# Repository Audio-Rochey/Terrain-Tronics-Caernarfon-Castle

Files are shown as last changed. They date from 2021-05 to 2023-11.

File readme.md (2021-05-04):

# TerrainTronics-Caernarfon-Castle

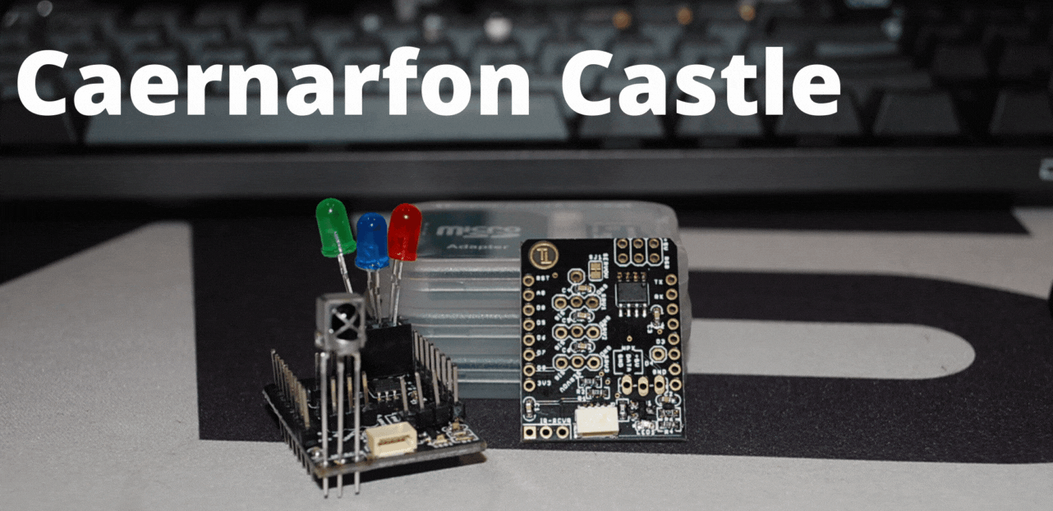
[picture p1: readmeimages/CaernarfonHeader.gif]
Image of Caernarfon Castle and the Small Circuit Board


## Version Data
Current release is version PG1.0. All features have been tested individually using standard Arduino libraries.

## Introduction

The TerrainTronics Caernarfon Castle board is designed to bring interaction to your terrain. The Caernarfon castle offers:
- Ability to drive 3x Servo Motors
- Infra-Red Remote Control Receiver
- 3 Onboard LED's
- Outputs for Neopixel (WS281x) Addressable LED's
- KeepAlive Circuit (pulls ~100mA every few seconds to keep a USB battery pack awake)
- QWIIC I2C Connector to connect to external sensors etc
- 

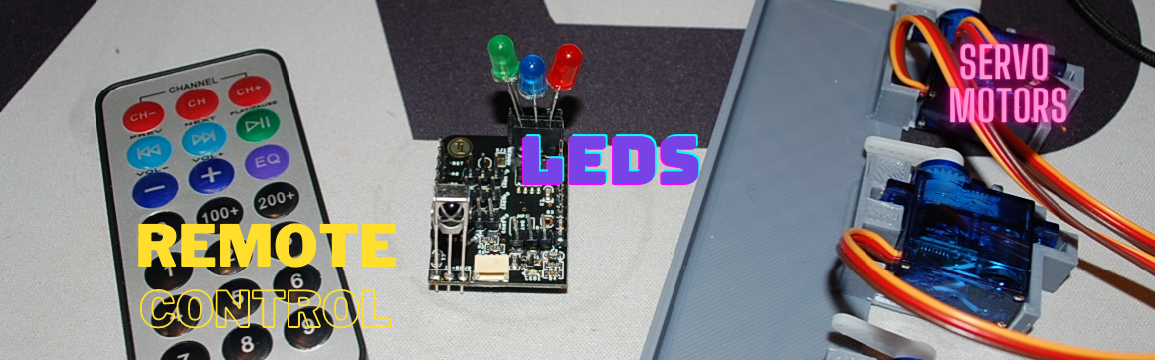
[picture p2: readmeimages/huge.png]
Image of the external features enabled by Caernarfon Castle


Onboard is the ability to drive 3 Servo Motors for moving gates, doors and other light bits of terrain, work with 3 LED's directly, and address a long chain of others, Change all the lights on your terrain RED when the situation changes, and with an IR Reciever, so you can use any old remote control to send messages to your terrain to respond. 

This makes it the ultimate tool for a DM (Dungeon Master) or GM (Games Master) to make their worlds interactive, to create puzzles with real, visible outcomes - prizes or punishments!

Code examples are constantly being developed and added here. 

**Please Note** - a Wemos D1 Mini board is required to control the Caernarfon Castle board. The Wemos D1 Mini is a small microcontroller board (using ESP8266) that has a standardized small form factor, wifi capability (if you want to use it) and the ability for it to be programmed using the Arduino programming environment. Whilst installing the Arduino programming environment is required to configure your setup - you can avoid the need for actual programming by copy/pasting some of the examples here.

## Pinout of the board

<table class="tg">
<thead>
  <tr>
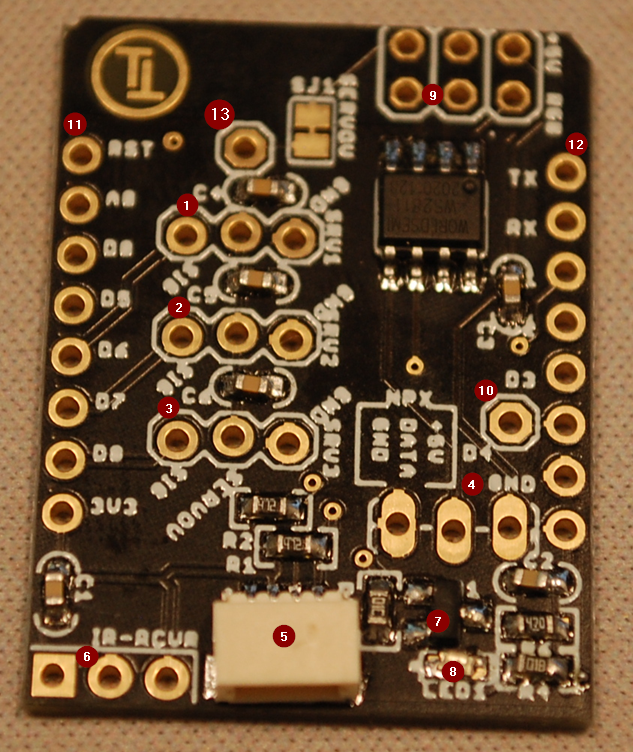
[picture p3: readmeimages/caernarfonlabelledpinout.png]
    <th class="tg-0pky" rowspan="14"></th>
    <th class="tg-0pky">Feature</th>
  </tr>
  <tr>
    <td class="tg-0pky">1. Servo Output (signal, power supply (5V), Ground) </td>
  </tr>
  <tr>
    <td class="tg-0pky">2. Servo Output</td>
  </tr>
  <tr>
    <td class="tg-0pky">3. Servo Output</td>
  </tr>
  <tr>
    <td class="tg-0pky">4. Neopixel output (GND, DataOut, +5V)</td> 
  </tr>
  <tr>
    <td class="tg-0pky">5. QWIIC I2C Connector</td>
  </tr>
  <tr>
    <td class="tg-0pky">6. IR Receiver - VS1838B - OUT, GND, VCC (+3.3V)</td>
  </tr>
  <tr>
    <td class="tg-0pky">7. KeepAlive Circuit</td>
  </tr>
  <tr>
    <td class="tg-0pky">8. Power Indicator (5V)</td>
  </tr>
  <tr>
    <td class="tg-0pky">9. LED Outputs from the first Neopixel</td>
  </tr>
  <tr>
    <td class="tg-0pky">10. Pin D4 output</td>
  </tr>
  <tr>
    <td class="tg-0pky">11. Left hand side strip to the Wemos D1 board</td>
  </tr>
  <tr>
    <td class="tg-0pky">12. Right hand side strip to the Wemos D1 board</td>
  </tr>
  <tr>
    <td class="tg-0pky">13. Alternative Servo Power Rail</td>
  </tr>
</thead>
</table>

| Pin | Notes about pin | Functionality |
|-----|---|---|
| D0  | No PWM possible | KEEPALIVE |
| D1  | Often used as SCL | I2C-SCL |
| D2  | Often used as SDA | I2C-SDA |
| D3  | No Pulldown allowed | NEOPIXEL OUT  |
| D4  | LED. No Pulldown Allowed | LED |
| D5  | Often used for SPI-CLK | IR IN |
| D6  | Often used for SPI-COPI | SERVO1 |
| D7  | Often used for SPI-CIPO | SERVO2 |
| D8  | No Pullup Allowed (Fail Boot). | SERVO3 |

the "notes about pin" come from the Wemos D1 Mini documentation. Effort has been made to make the Caernarfon Castle board compatible with other boards in the Terrain Tronics ecosystem, please note however that the Harlech Castle board cannot be used with the Caernarfon, as the IR IN and SPI-COPI (Controller Out Peripheral In) are used for different uses. However, Neopixels can be used in place of Harlech boards if needed.

## Unboxing and Assembly

Image of Caernarfon Box Contents

The Caernarfon Castle board is delivered without the pins having been soldered, however, you should find the pins in the package. This is to allow you to populate whichever pins are needed for the functionality that you are working towards, or, if system height is a concern, to solder wires directly into the holes.

The strips on the left and right hand side of the board are mandatory, to be used to stack and connect to a Wemos D1 Mini. Most Wemos D1 Mini boards are sold without soldered connectors either. In my experience it's easier to put female headers on the Wemos D1, then downard facing male connectors on the Caernarfon board. 

In the box, you will find:
1x Caernarfon Board
2x 40pin Pin headers
2x 8pin long leaded female headers
1x VX1838B IR Reciever

## Functionality

### Servo's (not included)
Image of an SG90 Servo
For motors that can turn an arm between 0 and 180 degrees, servo motors can be used. Servo motors have been used in model aircraft and train sets for years. They are quite easy to use, as you set the angle of deflection needed, and the servo motor will turn to that angle, and using it's own internal feedback, hold that position. The controller, or your software doesn't need to be concerned about measuring or holding the angle etc - simply tell the servo (using code) where to turn to - and it just does!
In the demo code, it's used as a gate to hold a boulder from rolling down and hurting the adventurers.

3 servo motors can be connected to the Caernarfon Castle board and can be addressed in Wemos D1 Arduino code on pins D5, D6 and D7. A library called Servo.h (a standard Arduino library) is used and can be downloaded from the internal GUI.

Servo's can be connected on to the 3-pin strips in the middle of the board. They should be connected as SIGNAL-POWER-GND. Most servo's are colour coded in Orange (Signal), Red (Power), Brown/Black (Ground). I've had some success with SG90 Servo's. They are the smallest kind on Amazon, but very usable.

### LED's (not included)
Image 3mm LED and of a Neopixel
The board has a WS2811 onboard. This is a chip that the wemos d1 board talks to with LED values. It has 4 outputs. 3 of them are for LED's and one (DOUT) is used to send on to the next in the chain. Such a daisy chain of LED's can pull a lot of current (power), so you may need an external 5V power supply that can provide enough current. For a handful of LED's, you should have no trouble.
Pin D3 is used to send data. The Adafruit NEOPIXEL library can be used to send data.

### I2C Output compatible with Sparkfun QWIIC and Adafruit Stemma QT (Connector onboard)
Image of Closeup of the connector
The board has a standardized I2C connector (4 pin SH connector). The SDA and SCL Pins (used for I2C) are mapped to pins D1 and D2. There are two 4K7Ohm resistors used as pullups. As this is just a connector, external devices will have to be programmed as and when you need them.
Breakout cables are available from Amazon, Sparkfun and Adafruit.

### USB Powerbank Keepalive circuit
Image of board with the size of the circuit
A transistor wired to put power through a small resistor is used to pull a surge of current every few seconds. This is used to convince some USB Power Banks to stay on, as many will go into a sleep mode and stop delivering power if there isn't enough power being drawn. The Keep Alive circuit pulls around 90mA-110mA when activated on pin D0.
No specific library is required to toggle pin D0, but be aware that the board is going to get hot quite quickly if you leave it on! 5V at ~100mA means approximately 0.5W of power will be dissipated in a device smaller than a grain of rice. Switch is on for a second, then off again! :)
In my code, I use the "ticker" library (#include <Ticker.h>). When you use a ticker function, you essentially set a software based timer that will run the code every few seconds (or however long you like). The accuracy isn't perfect, but it should be set to be often enough to keep a battery pack alive! :)

### Infra Red Reciever for remote control (included)
Image of the connector soldered correctly
Image of the device will the pins highlighted
VX1383B IR recievers are bundled with the kit. This IR reciever is designed to recieve most standard remote control signals and convert them into the electrical pulses that are decoded by the Wemos D1 Mini. 
Data is brought in on pin D5. 
I've used the IRremoteESP8266: IRrecvDemo to prove functionality. (it spits out the code driven by the remote on the computer screen). I then take that code (e.g. "FF30CF")
and change my code to respond in some way to that code - change the light, move a servo etc.
This allows you to use an off the shelf low cost remote control, or even recycle that remote control that in the junk drawer to control your terrain!
Care should be taken in which way the receiver is connected. Please see the image for reference. The reciever can be wired offboard if you want to hide your controller deep under the foam but show the IR reciever on a specific part of the terrain. 

## Schematic and Theory of Operation
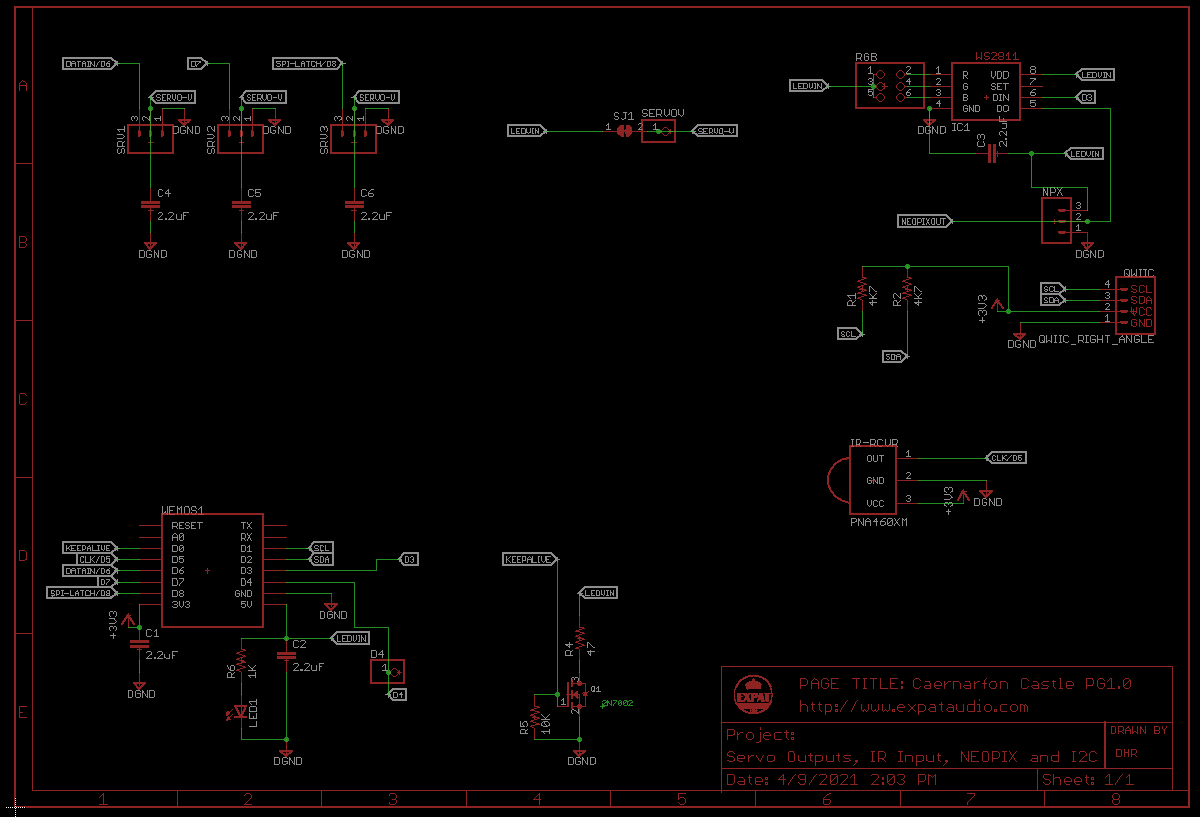
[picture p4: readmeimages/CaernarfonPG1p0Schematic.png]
Caernarfon Castle Board PG1p0 Schematic Caernarfon Schematic


[PDF OF THE SCHEMATIC](Caernarfon_Schematic_PG1p0.pdf)

** The text below is from the Conwy board -- need to rewrite ** 
The board functions a current source and 4 current mirrors.
R1,R2 and Q1 sets the reference current in the circuit.
Q2 through Q5 then mirror that current if they can. So an LED connected between the +5V (or your battery positive voltage) and the Drain (the top) of the transistor Q2-Q5 will switch on, then only allow the same amount of current through it that goes through Q1. E.g. if Q1 is set up for 10mA, then regardless of the color of the LED, only 10mA will be passed through it.

As mentioned in section 1 – each color LED drops a different voltage, but many are rated for the same brightness at a specific current.

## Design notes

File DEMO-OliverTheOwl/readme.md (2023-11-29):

# Oliver the Owl - Made by Terraintronics

IMAGE ALT TEXT HERE(https://www.youtube.com/watch?v=9bKIzAbPux4)

Oliver was inspired by WallyDM's Prismatic Owl puzzle.

The entire scene is powered by an 18650 Battery and Charger, available from TerrainTronics (https://www.tindie.com/products/32915/)

The USB Output of the board is connected to Oliver himself, using a USB cable and a hole in the floor.
A Direct 5V output from the board drives a Wemos D1 Mini that has a Harlech Castle 8ch LED Driver on top for driving the LED's that are around the terrain itself.

In the base, along with the battery is the Wemos D1 + Harlech, then each of yellow flickering LED's are connected to it. The setup code is simple and available on this gituhub folder.

## Oliver's Construction

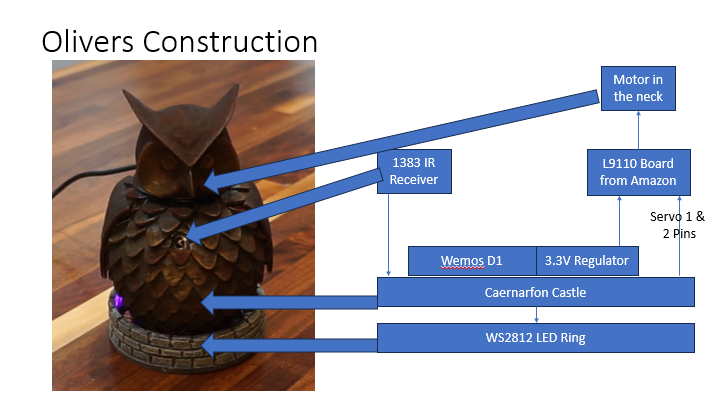
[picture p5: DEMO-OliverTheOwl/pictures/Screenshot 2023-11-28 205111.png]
Olivers Construction


Lightburn laser cutter files for Oliver are available from the special URL you receive when you buy from Terraintronics.

His base has a circular ring of WS2812 RGB LED's. They are soldered with wirewrap wire, then wire wrapped to a Caernarfon board.

The Caernarfon board connects is Servo Signal 1 and 2 pins to an L9110 Motor Driver Module from Amazon. That provides the right signals for the motor.

The motor is designed to run from 3.3V, so we need to drop the 5V from the USB on the Wemos D1 to 3.3V on the motor. The Wemos D1 already has a voltage regulator onboard, but I didn't want to risk pulling to much power and causing the Wemos D1 to crash! So an AMS1117 regulator module (again, Amazon was used).

> Written with [StackEdit](https://stackedit.io/).

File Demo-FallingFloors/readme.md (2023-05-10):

# Terrain Tronics Gauntlet Challenge!

The contents of this directory go along with a video from 

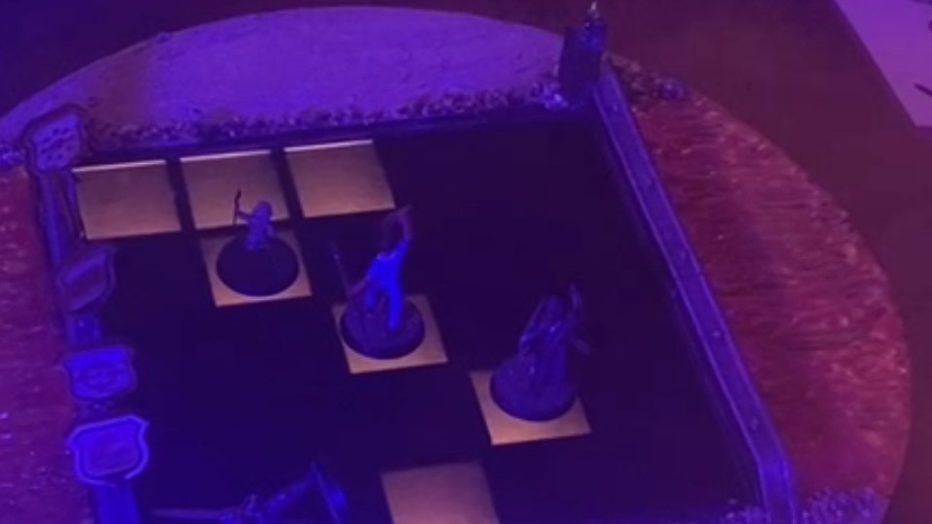
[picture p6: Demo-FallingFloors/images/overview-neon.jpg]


## Features

- 50 RGB LED's in an array of 25 cells, each with 2 RGB LED's in them.
- Ir Remote control for the DM that can:
* Reset the playfield with a random, hidden path
* Remove 1 of 3 options (if DM wants to challenge players with a riddle, skillcheck etc)
* Step to the next row.

## What's in this directory?

- Arduino code to run on the WemosD1 Mini. (ino file, bin file etc). The BIN file can be uploaded, AS IS, using the TerrainTronics upload tool.
- SVG / Lightburn files for the foam and wood parts to be cut out.
- 3D printable files (STL) for parts of the bridge, and the "pizzaswitchandsimpleUSBconnector"

## How does all this work?
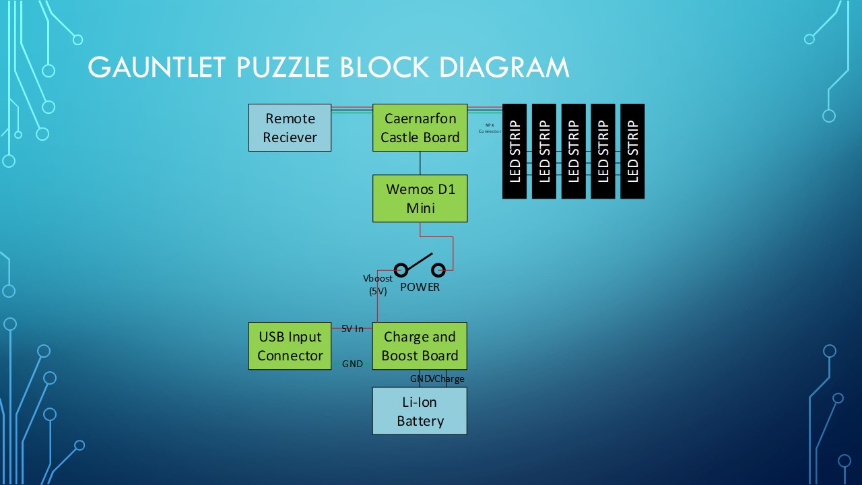
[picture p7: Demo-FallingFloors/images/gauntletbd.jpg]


### Brains and Lights
The playfield is made up of a string of RGB LED's (WS2812B RGB LED's), easily available from Amazon. I picked 60 per Meter, so that a pair of them roughly takes 30mm, close enough to the typical D&D 25.4mm spacing.

The brain is the Arduino compatible Wemos D1 Mini. Based on the infamous ESP8266 Wifi processor, the D1 Mini has a lot of power, a lot of capabilities, small form factor and fairly priced on Amazon.

On top, acting as an interface to the IR Remote control receiver and the interface to the RGB LED's is a Caernarfon Castle PCB board from TerrainTronics. It comes pre-assembled and tested, the only work you have to do is soldering the pins you want to connect to the Wemos D1 Mini.

I typically set the Wemos D1 with Female Headers and use the Caernarfon board with Male headers pointing down into the Wemos D1.
You'll also need to add headers for the NPX Output connector. (NeoPixel - a nerdy term for those RGB LED's) and the IR Receiver.

### Power
I had more fun trying to work out the power tree of this darn thing!
I used a rechargable Lithium Ion battery in my build. If I did it again, I would look for a battery that could support at least 2000mAH. (milli amp hours).

The Chinese electronic module makers have started selling "charge/discharge boards" - these are awesome because they handle all the battery charging concerns. You bring in 5V (from, say, a USB source), you connect your battery (typically a 3.7Volt) and it has an integrated booster, to kick in the 3.7V up to 5V.

WS2812B RGB LED's all require 5V supplies. They are a nuisance! :)

- The USB input connector is always connected to the Charge/Discharge board. That makes sure that even if the lights are off, you can charge the terrain.
- The power switch sits between the output of the CH/Disch board and the Wemos D1 Mini/Caernarfon combination.

## Software

The Arduino IDE is used for developing the software, if you want to tweak it or use it with a different remote control.
You'll need to download the following files:
### 

 - [Caernarfon-FloorPanelProto.ino](https://github.com/Audio-Rochey/Terrain-Tronics-Caernarfon-Castle/blob/main/Demo-FallingFloors/Caernarfon-FloorPanelProto.ino)
 - [buttonfunctions.h](https://github.com/Audio-Rochey/Terrain-Tronics-Caernarfon-Castle/blob/main/Demo-FallingFloors/buttonfunctions.h)
 - [buttonfunctions.ino](https://github.com/Audio-Rochey/Terrain-Tronics-Caernarfon-Castle/blob/main/Demo-FallingFloors/buttonfunctions.ino)

Setting up the Arduino IDe to support the Wemos D1 Mini can be seen in this video: https://www.youtube.com/watch?v=TgE-Op0UvxE

The software is fairly understandable, but if you're struggling, you're welcome to find terraintronics on facebook and ask any questions on the facebook group.

## Physical Build

Lightburn files for laser engraving are in this directory, along with SVG conversions of them. The disc is actually 300mm in diameter, a little less than 12 inches.

> Written with [StackEdit](https://stackedit.io/).

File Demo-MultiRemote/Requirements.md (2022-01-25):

## Caernarfon Castle "Universal" Remote Control code.

Designed to be the default code that ships on TerrainTronics sourced Wemos D1 boards. The code is made for arduino and has 3 files that are part of the code.

Arduino remote

The buttons on the remote control do the following:

| Button | Code | Function |
| --- | --- | --- |
|Prev|FF22DD|Motor A One Direction by 15 degrees |
|Next|FF02FD|Motor A Other Direction by 15 degrees |
|VOL-|FFE01F| Global Brightness Control - (Default Max Power) |
|VOL+|FFA857| Global Brightness Control + (Default Max Power) |
|0|FF6897| All LEDS OFF |
|1|FF30CF| Motor A Toggle 180 Degrees |
|2|FF18E7| Motor B Toggle 180 Degrees |
|3|FF7A85| Motor C Toggle 180 Degrees |
|4|FF10EF| All Lights Red |
|5|FF38C7| LED Strip Flicker like candles |
|6|FF7A85| Lava Effect |
|7|FF42BD| TBD |
|8|FF4AB5| TBD |
|9|FF52AD| TBD |

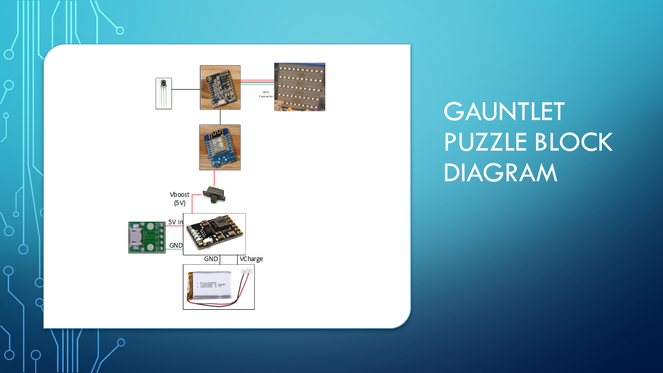
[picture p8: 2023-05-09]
Demo-FallingFloors/Puzzle Part Pictures.png

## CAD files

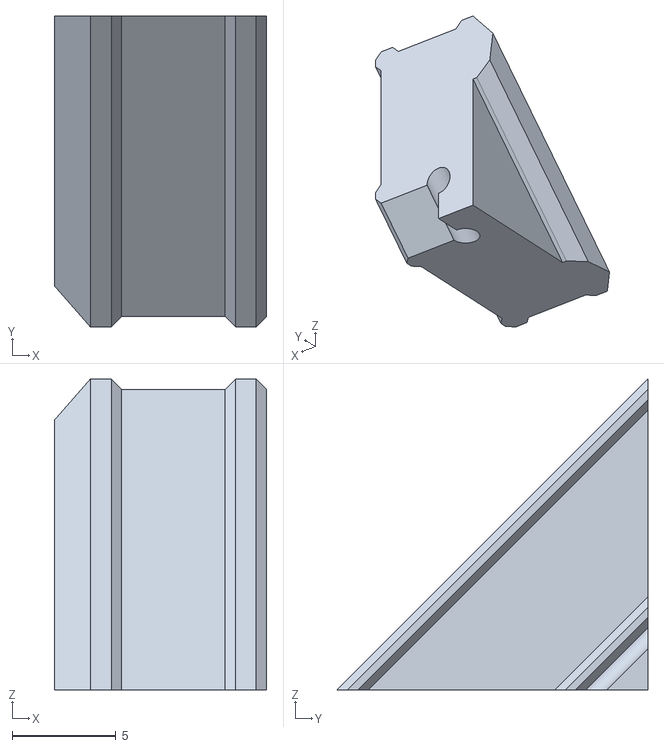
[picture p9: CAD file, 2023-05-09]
Demo-FallingFloors/norsebridgecapleft.stl
10.2 x 15.0 x 15.0

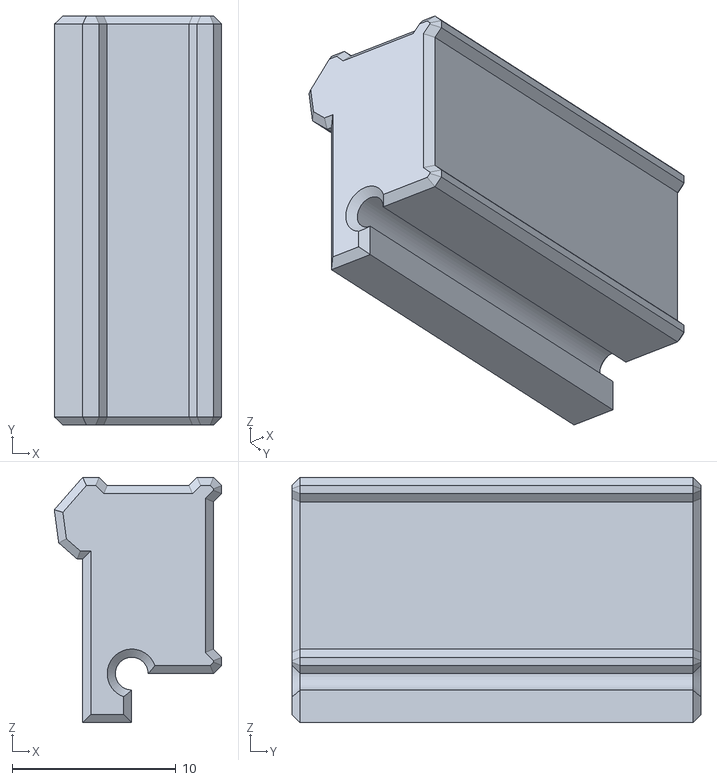
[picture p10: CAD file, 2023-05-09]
Demo-FallingFloors/norsebridgesegment.stl
10.2 x 25.0 x 15.0

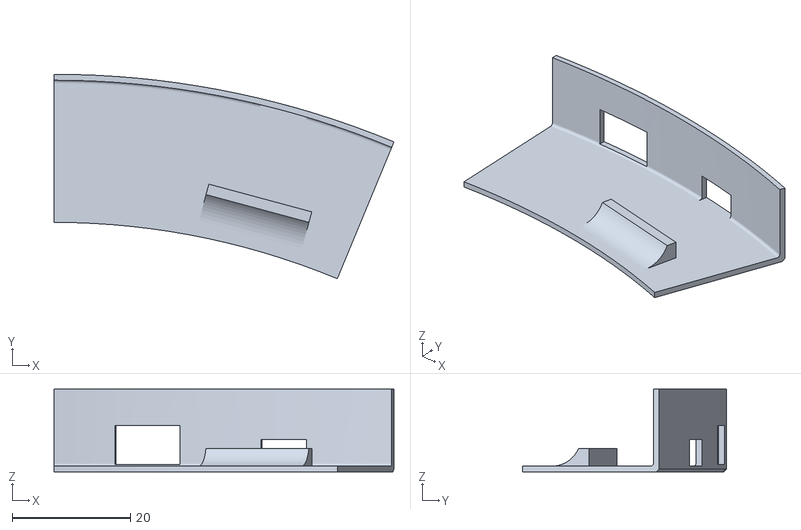
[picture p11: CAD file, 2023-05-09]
Demo-FallingFloors/pizzaswitchandsimpleusbconnector.stl
57.4 x 34.5 x 14.0

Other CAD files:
Demo-FallingFloors/norsebridgecapright.stl

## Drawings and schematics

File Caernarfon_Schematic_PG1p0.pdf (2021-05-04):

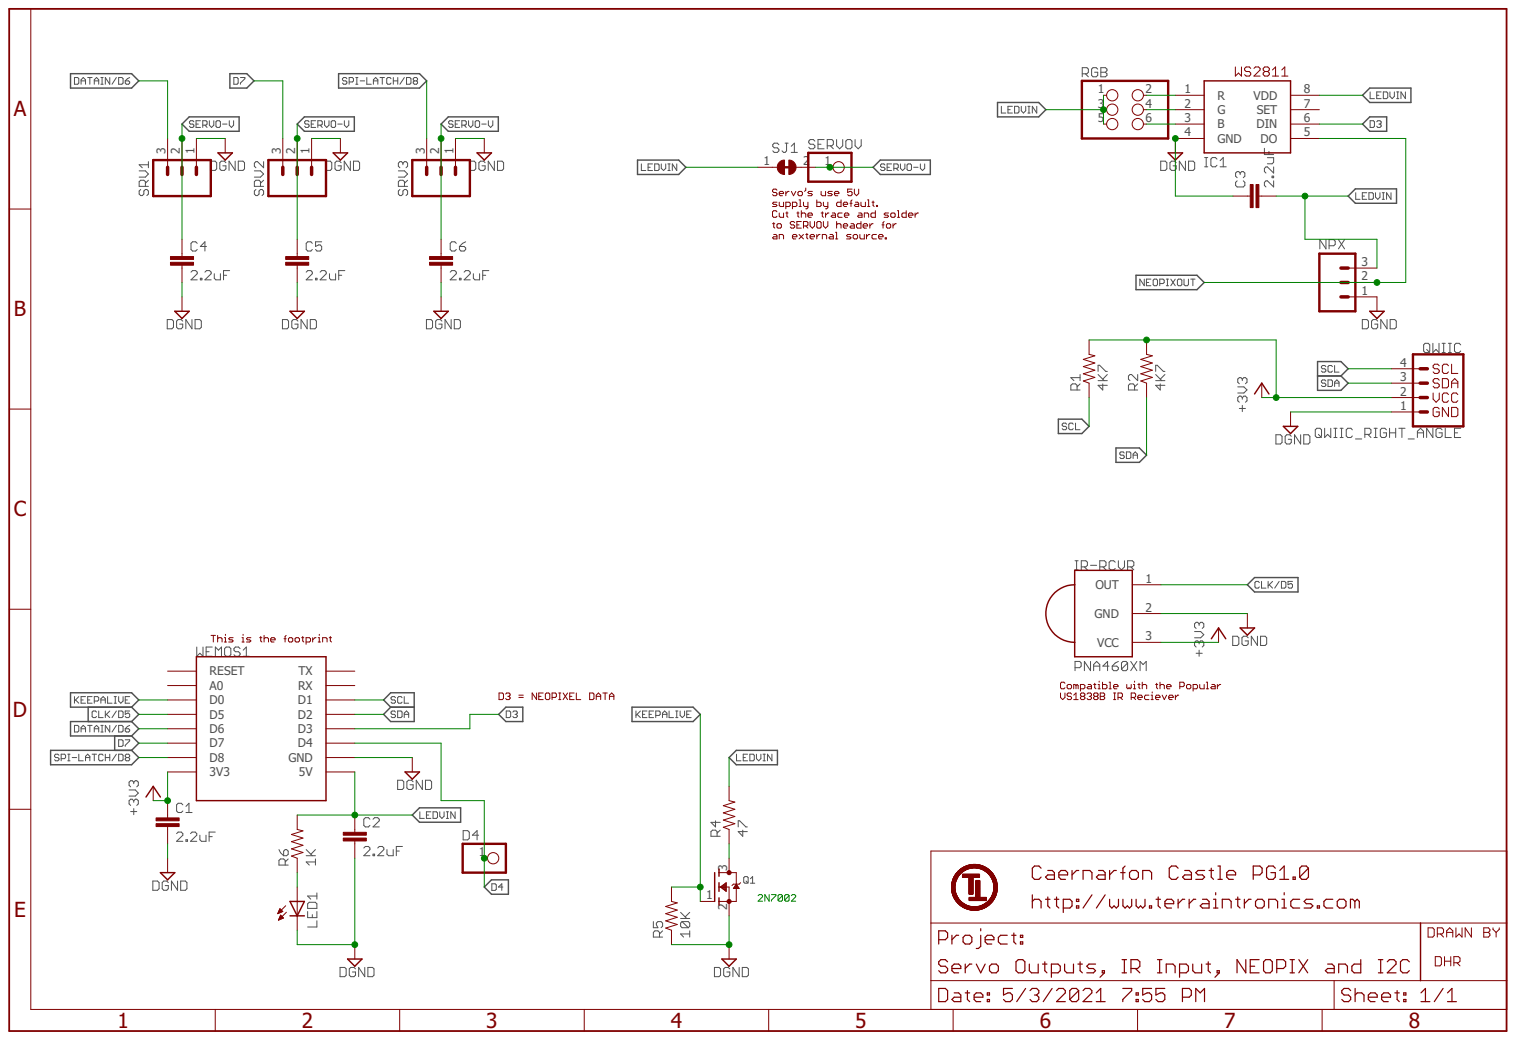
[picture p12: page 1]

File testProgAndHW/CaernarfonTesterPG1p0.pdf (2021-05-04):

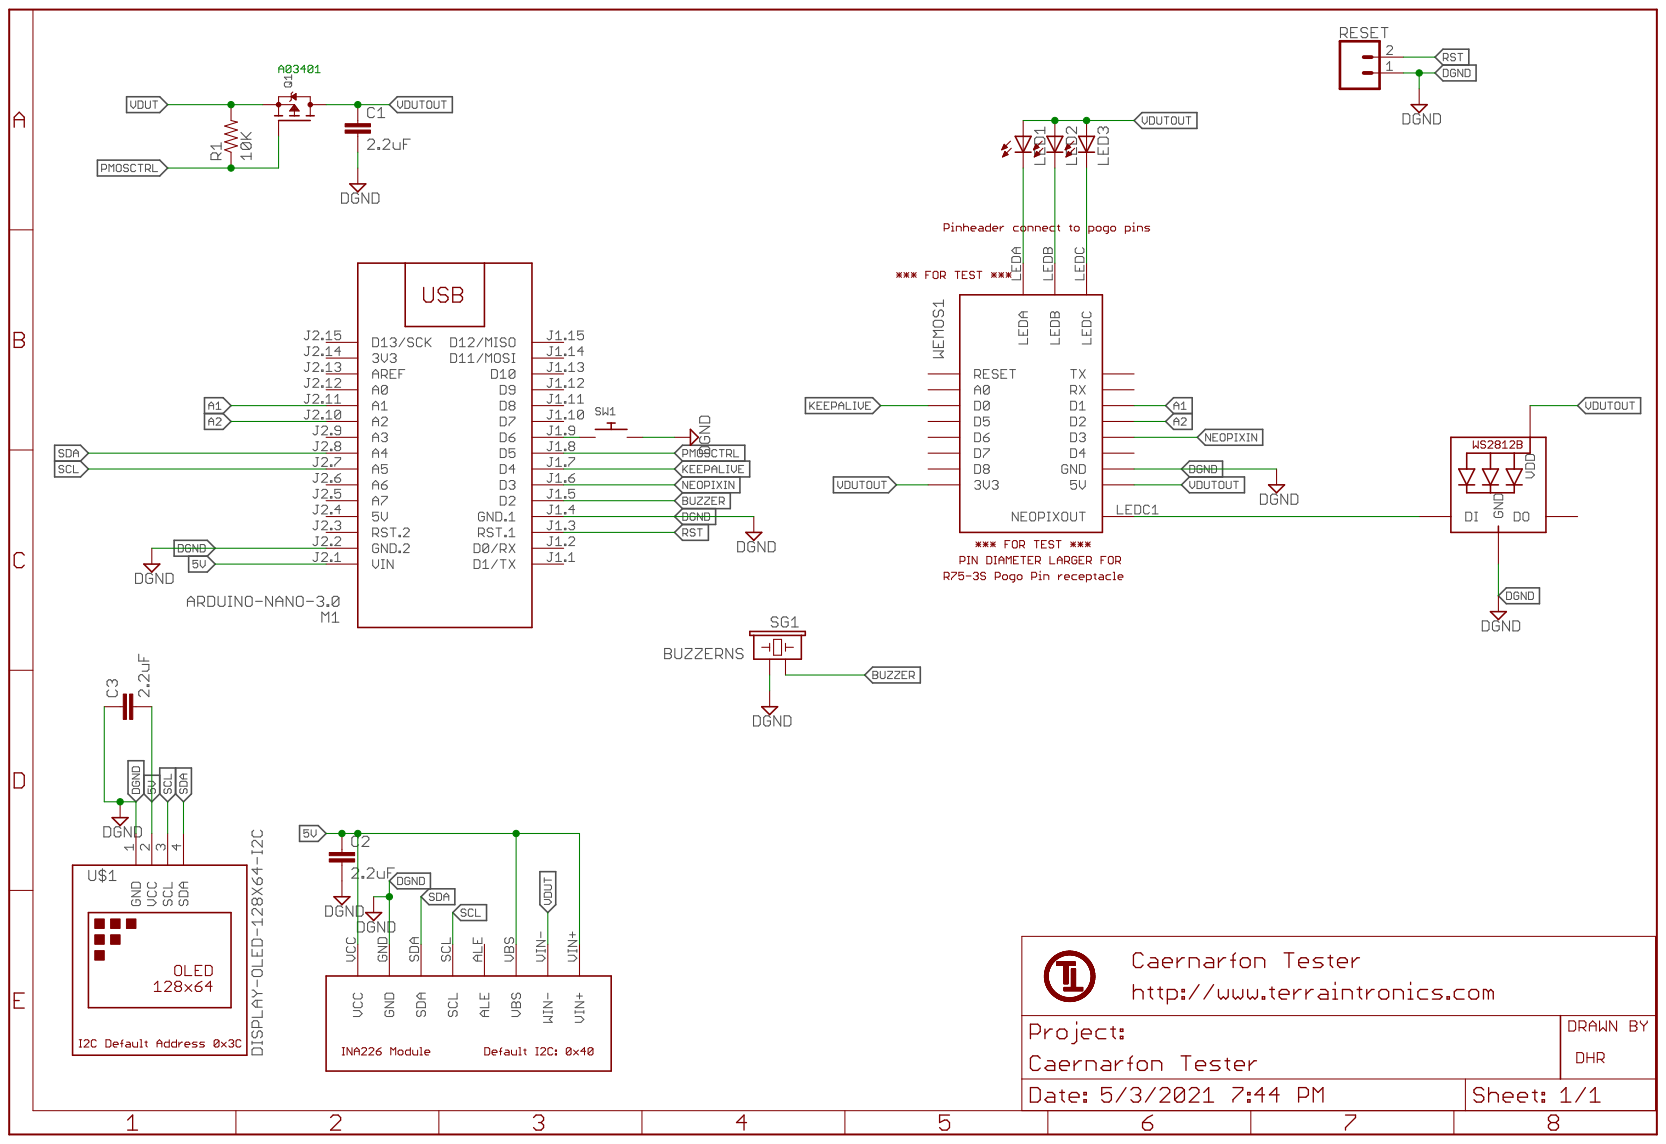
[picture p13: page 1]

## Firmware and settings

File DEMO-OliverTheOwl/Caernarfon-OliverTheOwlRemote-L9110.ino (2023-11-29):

/*
 * 1/24/2022 -- building upon the initial version.
 * This code uses 2 external files within arduino and will define the functionalty for almost every button the remote.
 * Here are the requirements:https://github.com/Audio-Rochey/Terrain-Tronics-Caernarfon-Castle/blob/main/Demo-MultiRemote/Requirements.txt
 * 
 * I followed this video to learn how to split the files in arduino: https://www.youtube.com/watch?v=BdstuZP6l5E
 * However, rather than namign files .cpp, i used INO.
 * 
 * This is the work done for Oliver the Owl (the actual NPC himself, not the room he's in!)
 * Wemos D1+ Mini +_ Caernarfon Castle, then Servo signal 1 and 2 are connected to the inputs to a 
 * 
 * Description of states:
 * ledState Zero is All Lights Off
 * ledState One is all Red.
 * ledState Two is flicker. (which gets updated in the main loop.
 * ledState Three is lava
 * ^^^ this was previously used to toggle the states.
 * 
 * trapOneState between 0 and 1 used to 
 *  * This work is based on the Servo for ESP8266 and the IRremoteESP8266: IRrecvDemo 
 * 
 * Wifi library is used to put it to sleep ASAP. Addd Feb 1st 2022. * 
 * 
 * Dafydd Roche - 2/1/2022
 * 
 * Remote control to switch on some gates.
 * https://amzn.to/2Qc9BI0
 * 
 * Wemos D1 mini.
 * D5 connected to VOUT of the IR reciever
 * D6,D7,D8 connected to the VIN of 3 servos.
 * Neopixel Data out on D3.
 * Keepalive isn't used.
 * 
 * 
 * UPDATES IN V2
 * - Handle REPEAT (0xFFFFFFF) commands
 *      When the (results.value == 0xFFFFFFFFFFFFFFFF) replace results.value with lastCommand.
 *      else, you have a decent IR recieve - make it the "lastCommand".
 *      Toggle a bolean if it's a repeat, so it can be looked at by any function.
 */

#include <Arduino.h>
#include <IRremoteESP8266.h>
#include <IRrecv.h>
#include <IRutils.h>
#include <Adafruit_NeoPixel.h>
#include <ESP8266WiFi.h> // added Feb 1st 2022
// Required for LIGHT_SLEEP_T delay mode
extern "C" {
#include "user_interface.h"
}


#include "buttonfunctions.h" // put the functions for each button in a separate file.

int trapOneState;
int trapOnePos;
int trapTwoState;
int trapTwoPos;
int trapThreeState;
int trapThreePos;

bool OgmoreState;

const String softwareVersion = "V1";
const String softwareDate = "3/22/2022 / checked 11/28/2023";     
const String CaernarfonVer = "1p0";
const int keepAlive = D0;// The Keepalive pin for USB Power Banks is D0, but isn't used in this demo
const String keepAlivePin = "D0";

#define LED_PIN    D3
#define LED_COUNT 51 // remember that there's one on the board. (A WS2812 chip to be exact)
//Adafruit_NeoPixel strip(LED_COUNT, LED_PIN, NEO_GRB + NEO_KHZ800);  // - for WS2812
Adafruit_NeoPixel strip(LED_COUNT, LED_PIN, NEO_RGBW + NEO_KHZ800);


// An IR detector/demodulator is connected to GPIO pin 14(D5 on a NodeMCU
// board).
// Note: GPIO 16 won't work on the ESP8266 as it does not have interrupts.
const uint16_t kRecvPin = D5;

IRrecv irrecv(kRecvPin);

decode_results results;

int ledState = 0;
unsigned long ledPreviousMillis = 0;        // will store last time LED was updated
long flickerLedInterval = 0;                // this will be updated with every flicker.

unsigned long lavaPreviousMillis = 0;        // will store last time LED was updated
long lavaLedInterval = 0;                // this will be updated with every flicker.


int globalBrightness = 127; // start at half max brightness


// sleep counter numbers
unsigned long sleepConstantMillis = 7200000;        // lights will go to sleep after 2 hours seconds to save power. (1 hour = 3600000 timer ticks)
unsigned long sleepLastChangeMillis ;             // Variable that tracks when the system was last interacted with.

unsigned long lastCommand ;  // define a variable for the previous decent command that isn't a repeat
bool repeatedCommand = 0; // Repeated command (0xFFFFFFFFFFFFFFFF) sets this to 1.

void setup() {
  WiFi.disconnect();     // We're not using Wifi, so lets disable it to save power.
  WiFi.forceSleepBegin();
  delay(1); //For some reason the modem won't go to sleep unless you do a delay.


  
  strip.begin();           // INITIALIZE NeoPixel strip object (REQUIRED)
  strip.show();            // Turn OFF all pixels ASAP
  strip.setBrightness(globalBrightness); // 

  strip.setPixelColor(0, random(146,164), random(90,109), 0);
  strip.setPixelColor(1, random(146,164), random(90,109), 0);
  strip.setPixelColor(2, random(146,164), random(90,109), 0);
  strip.setPixelColor(3, random(146,164), random(90,109), 0);
  strip.show(); 


  Serial.begin(115200);
  irrecv.enableIRIn();  // Start the receiver
  while (!Serial)  // Wait for the serial connection to be establised.
    delay(50);
  Serial.println();
  delay(1000);
  Serial.println("*****");
  delay(100);
  Serial.println("TerrainTronics Demo - Oliver the Owl");
  Serial.print("Version ");
  Serial.print(softwareVersion);
  Serial.print(" Date of Compile ");
  Serial.print(softwareDate);
  Serial.print(" Caernarfon HW Version ");
  Serial.println(CaernarfonVer);
  Serial.print("IRrecv: ");
  Serial.println(kRecvPin);
  Serial.print("LED Count: ");
  Serial.println(LED_COUNT);
  pinMode(D6, OUTPUT);//Set the Servo1,2,3 on Caernarfon board as outputs.
  pinMode(D7, OUTPUT);
  pinMode(D8, OUTPUT);

    delay(500);


  sleepLastChangeMillis = millis();

  //Just making it turn on poweron.
  digitalWrite(D7, LOW);
  digitalWrite(D6, LOW);

  
}

void callback() {
  Serial.println("WAKE FROM IR!");
  irrecv.enableIRIn(); // Reconfigures timers etc on the device to accept IR (e.g. timer to 50uS to sample the input etc)

}

void loop() {
  unsigned long currentMillis = millis();



  // Checks if any led's have been pressed for the last sleepConstantMillis. If so, switch the LED's off.
  // sleepLastChangeMillis is updated every time an IR message is recieved.
  if (currentMillis - sleepLastChangeMillis >= sleepConstantMillis) {
      ledState = 0;
      ledUpdate(0);
      Serial.println("Auto Lights Off");


      // This code (added Feb 2022). It puts the device to sleep and wakes ut up if there's any activity on the IR recieve pin.
      // This then runs the callback function - which reconfigures the timers etc to accept IR.
      // That means that the first time you push an IR button, you wake the device, but no legitimate command. Push the button again and it'll wake up.
      gpio_pin_wakeup_enable(GPIO_ID_PIN(kRecvPin), GPIO_PIN_INTR_LOLEVEL);
      wifi_set_opmode(NULL_MODE);
      wifi_fpm_set_sleep_type(LIGHT_SLEEP_T);
      wifi_fpm_open();
      wifi_fpm_set_wakeup_cb(callback);
      wifi_fpm_do_sleep(0xFFFFFFFF);
      delay(100);

     WiFi.disconnect();     // After it comes back out of deep sleep, lets disconnect the wifi etc to make sure we're getting lower power
     WiFi.forceSleepBegin();
     delay(1); //For some reason the modem won't go to sleep unless you do a delay.
  }
  
  // this is the only LED update that's handled on every loop - as it randomizes the colors.
  if ((ledState == 2)&&(currentMillis - ledPreviousMillis >= flickerLedInterval)) { // if we're in mode 2, AND the current-prev time is more than the flicker
    // save the last time you blinked the LED
    ledPreviousMillis = currentMillis; // resets the timer.
    int currLED = 0;
    for (currLED = 0; currLED <= LED_COUNT; currLED++) {
      strip.setPixelColor(currLED, random(146,164), random(90,109), 0);
    }
    strip.show();   
    flickerLedInterval = random(50,100);
  }


  if ((ledState == 3)&&(currentMillis - lavaPreviousMillis >= lavaLedInterval)) { // if we're in mode 2, AND the current-prev time is more than the flicker
    // save the last time you blinked the LED
    lavaPreviousMillis = currentMillis; // resets the timer.
    int currLED = 0;
    for (currLED = 0; currLED <= LED_COUNT; currLED++) {
      int j = random(0,63); // 10 in 64 chance that there will be flicker that isn't pure red.
      if (j < 6) {
        strip.setPixelColor(currLED, 150, random(0,30),random(0,3));
    
      }
      else {      strip.setPixelColor(currLED, 255, 0, 0);
    }
    }
    strip.show();   
    lavaLedInterval = random(250,500);
  }
  
  if (irrecv.decode(&results)) {

    // ACTIVITY! RESET THE TIMER!
    sleepLastChangeMillis = millis();
  
    // print() & println() can't handle printing long longs. (uint64_t)
    Serial.print("IR Recieve: ");
    serialPrintUint64(results.value, HEX);
    Serial.println("");


    //delay(150); // add a delay for debounce (stops repeats)
    
    if (results.value == 0xFFFFFFFFFFFFFFFF) { // if it IS the repeat.
      repeatedCommand = 1; // potentially used in each function.
      Serial.println("Repeated");
      results.value = lastCommand; // replaces the FFFF's wiht the last command.
      Serial.print("FFF's replaced with: ");
      serialPrintUint64(results.value, HEX);
      Serial.println("");
    }
    else{ // is a legit command.
      repeatedCommand = 0; // potentially used in each function.
      lastCommand = results.value; // writes the good command to the lastCommand, in case the next one is a repeat.
    }
    
    if (results.value == 0xFF02FD) { // Rotate the MOtor in 1 direction for 250mS
      digitalWrite(D6, HIGH);
      digitalWrite(D7, LOW);
      delay(250);
      digitalWrite(D6, LOW);  
      
    }

    if (results.value == 0xFF22DD) { // Rotate the MOtor in the other direction direction for 250mS
      digitalWrite(D7, HIGH);
      digitalWrite(D6, LOW);
      delay(250);
      digitalWrite(D7, LOW);  

    }
    
    if (results.value == 0xFFE01F) { // Arduino Remote Vol- lower the brightness in half.
      globalBrightness = (globalBrightness/2);
      if (globalBrightness < 1 ) { globalBrightness = 1; }
      strip.setBrightness(globalBrightness);
      strip.show();
    }

    if (results.value == 0xFFA857) { // Arduino Remote Vol+ Double the brightness.
      globalBrightness = (globalBrightness*2);
      if (globalBrightness > 255) { globalBrightness = 255; }
      strip.setBrightness(globalBrightness);
      strip.show();
    }
    
    if (results.value == 0xFF6897) { // Button 0 - only runs if this is the code pressed
      buttonZERO();
    }    
    if (results.value == 0xFF30CF) { // Button 0 Toggle Motor A all the way one way or the other (e.g. a sliding door)
      buttonONE();
    }
    if (results.value == 0xFF18E7) { // Button 2 Toggle Motor B all the way one way or the other (e.g. a sliding door)
      buttonTWO();
    }
    if (results.value == 0xFF7A85) { // Button 3 Toggle Motor C all the way one way or the other (e.g. a sliding door)
      buttonTHREE();
    }
    if (results.value == 0xFF10EF) { // Button 4 All Lights Red
      buttonFOUR();
    }
    if (results.value == 0xFF38C7) { // Button 5 All LED's Flicker Yellow etc. 
      buttonFIVE();
    }
    if (results.value == 0xFF5AA5) { // Button 6  
      Serial.println(" Button 6 - Lava ");
      buttonSIX();
    }
    if (results.value == 0xFF42BD) { // Button 7  - can be used to switch an Ogmore USB swithc etc -- but not used on Oliver.
      Serial.println(" Button 7 - No Command ");
      digitalWrite(D8, OgmoreState);
      OgmoreState = !OgmoreState;
    }
    if (results.value == 0xFF4AB5) { // Button 8  
      Serial.println(" Button 8 - No Command ");
    }
    if (results.value == 0xFF52AD) { // Button 9  
      Serial.println(" Button 9 - No Command ");
    }



  

    irrecv.resume();  // Receive the next value
  }
    
}

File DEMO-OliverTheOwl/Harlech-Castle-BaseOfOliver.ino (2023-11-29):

//**************************************************************//
//  Name    : Harlech Castle Oliver the owl's Den                    //
//  Author  : Dafydd Roche                                      //
//  Date    : 11/28/23                                       //
//  Version : 1.0                                               //
//  Notes   : This code runs on the Wemos D1 Mini.              //
//            This code does not use any of the Wifi            //
//              Capabilities                                    //
//****************************************************************

/* Simple Mods possible on Harlech Castle board.
 * 
 * Use WireWrap to connect the IR Reciever to 3.3V, GND and D3.
 * Then can we WW'd to the pin headers on Wemos Board, then stack the Harlech board on top.
 * 
 * 
 * 
 * Cheers
 * 
 * TerrainTronics
 * 
 * 
 */





#include <ESP8266WiFi.h> // This allows the modem to be powered off, saving 40mA!
#include <Arduino.h>
#include <IRremoteESP8266.h>
#include <IRrecv.h>
#include <IRutils.h>
extern "C" {
#include "user_interface.h"
}
#include<math.h>

const String softwareVersion = "V1.0";
const String softwareDate = "1/17/2023";     
const String HarlechVer = "1p1";

// This sets up the USBBank Keep Alive Functionality. By default, this is set to 100mA of additional current, for 1S every 10.
#include <Ticker.h>  //Ticker Library
Ticker USBBank;
int USBBankState = 0;
const int keepAlive = D0;// The Keepalive pin for USB Power Banks is D0. UPdates in Harlech 1.1
const int kaTimeOn = 1; // Time to switch the keep alive circuit on.
const int kaTimeOff = 8; // Time to switch the keep alive circuit off for.

// #define DEBUG 0 // this is used to switch debug comments on and off. Comment it out with // to optimize the code.

 
// These constants won't change. They're used to give names to the pins used:
const int analogInPin = A0;  // Analog input pin that the potentiometer is attached to.

int patternData = 0;
int dutyCycle = 1023;  

//These definitions configure the pins for the SPI interface to talk to the LED driver
int latchPin = D8; // Checked with PG1.1 of Harlech
int clockPin = D5; // Checked with PG1.1 of Harlech
int dataPin = D6; // Checked with PG1.1 of Harlech
int OE = D7; // Set the output enable pin. This can be rapidly PWM'd. Checked with PG1.1 of Harlech. (Soldered to lower 2)
int OEBrightness = 0;
int OEBrightnessIndex = 1;

const uint16_t kRecvPin = D3;
IRrecv irrecv(kRecvPin);
decode_results results;



//=======================================================================
// This is a subroutine that switches the keepAlive pin on/off to switch on a transistor that pulls current to ground, through a 47Ohm resistor
// PLEASE NOTE: You cannot leave this on for a long long time, as the resistor will begin to heat up beyond it's rating!

void keepAliveChangeState()
{
  //Serial.println("Keepalive Change");
  if (USBBankState == 0 ){
    //Serial.println("Switching off");
    USBBankState = 1;
    digitalWrite(keepAlive, 0); // Switch Transistor Off
    USBBank.attach(kaTimeOff, keepAliveChangeState); //Use attach_ms   
  }
  else if (USBBankState == 1 ){
    //Serial.println("Switching on");
    USBBankState = 0;
    digitalWrite(keepAlive, 1); // Switch Transistor On
    USBBank.attach(kaTimeOn, keepAliveChangeState); //Use attach_ms   
  }
}




void setup() {
  
  WiFi.disconnect();     // We're not using Wifi, so lets disable it to save power.
  WiFi.forceSleepBegin();
  delay(1); //For some reason the modem won't go to sleep unless you do a delay
  
  
  

  Serial.begin(115200);
  irrecv.enableIRIn();  // Start the receiver
  while (!Serial)  // Wait for the serial connection to be establised.
    delay(50);
  Serial.println();
  delay(1000);
  Serial.println("*****");
  delay(100);
  Serial.println("TerrainTronics Demo - Generic Remote Control Standard");
  Serial.print("Version ");
  Serial.print(softwareVersion);
  Serial.print(" Date of Compile ");
  Serial.print(softwareDate);
  Serial.print(" Harlech Hack HW Version ");
  Serial.println(HarlechVer);
  Serial.print("IRrecv: ");
  Serial.println(kRecvPin);

  pinMode(latchPin, OUTPUT);
  pinMode(clockPin, OUTPUT);
  pinMode(dataPin, OUTPUT);

  pinMode(keepAlive, OUTPUT);     // KeepAlive pin needs pulling low, otherwise it'll float up
  digitalWrite(keepAlive, LOW);   // and switch on the transistor. - THIS IS IMPORTANT, OTHERWISE IT FLOATS UP AND SWITCHES THE TRANSISTOR ON!

  USBBank.attach(1, keepAliveChangeState); // This starts the timer for the USB Power Bank Keepalive.

  patternData = 0xFF;
  OEBrightness = 1;
  delay(10000);
}

void callback() {
  Serial.println("WAKE FROM IR!");
  irrecv.enableIRIn(); // Reconfigures timers etc on the device to accept IR (e.g. timer to 50uS to sample the input etc)

}
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

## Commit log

2022-02-01 updated to version 1.1
    added a two hour timeout.
    Switches lights off after two hours.
    IR can wake up the system easily.
2023-03-03 Create Caernarfon-TTW-Mountain.ino
    Initial upload of code. See Johns video at: https://www.youtube.com/watch?v=cYuFJSO46kM
